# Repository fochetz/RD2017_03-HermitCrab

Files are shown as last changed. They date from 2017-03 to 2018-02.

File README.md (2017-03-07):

# RD2017_03-HermitCrab

N|Solid (https://nodesource.com/products/nsolid)

Hermit Crab is an autonomous Arduino based robot which can interact with people in order to promote a fish restaurant.
Our idea is to build more than one robot with the appearance of hermit crabs that will be able to move, to understand when a person is approaching them and to react hiding under their own shells.
Then they will start slowly to come out from the shell and start to do some movements attracting attention with sound and light.

## Multidisciplinary Course of Robotics and Design - 5th Edition
Professors:
 - Andrea Bonarini, DEIB department, Politecnico di Milano
 - Maximiliano Romero, DPAC department, Università IUAV, Venezia

Tutors: Andrea Brivio, Yael Bendit

## Team
 - Moreno Sardella, master degree student in computer science
 - Luca Fochetta, master degree student in computer science
 - Dimitar Anastasovski, master degree student in computer science
 - Lorenzo Vignati, master degree student in biomedical science
 - Paolo Ritter, master degree student in biomedical science

**... free software, hell yeah!**

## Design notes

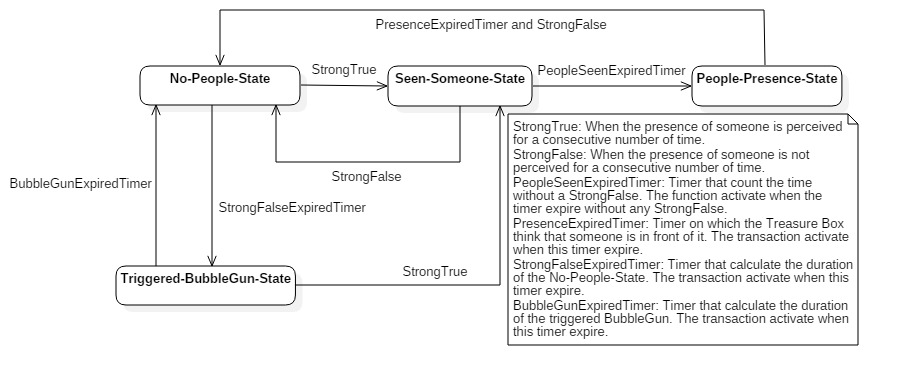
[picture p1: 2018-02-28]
documents/OysterDiagram.jpg

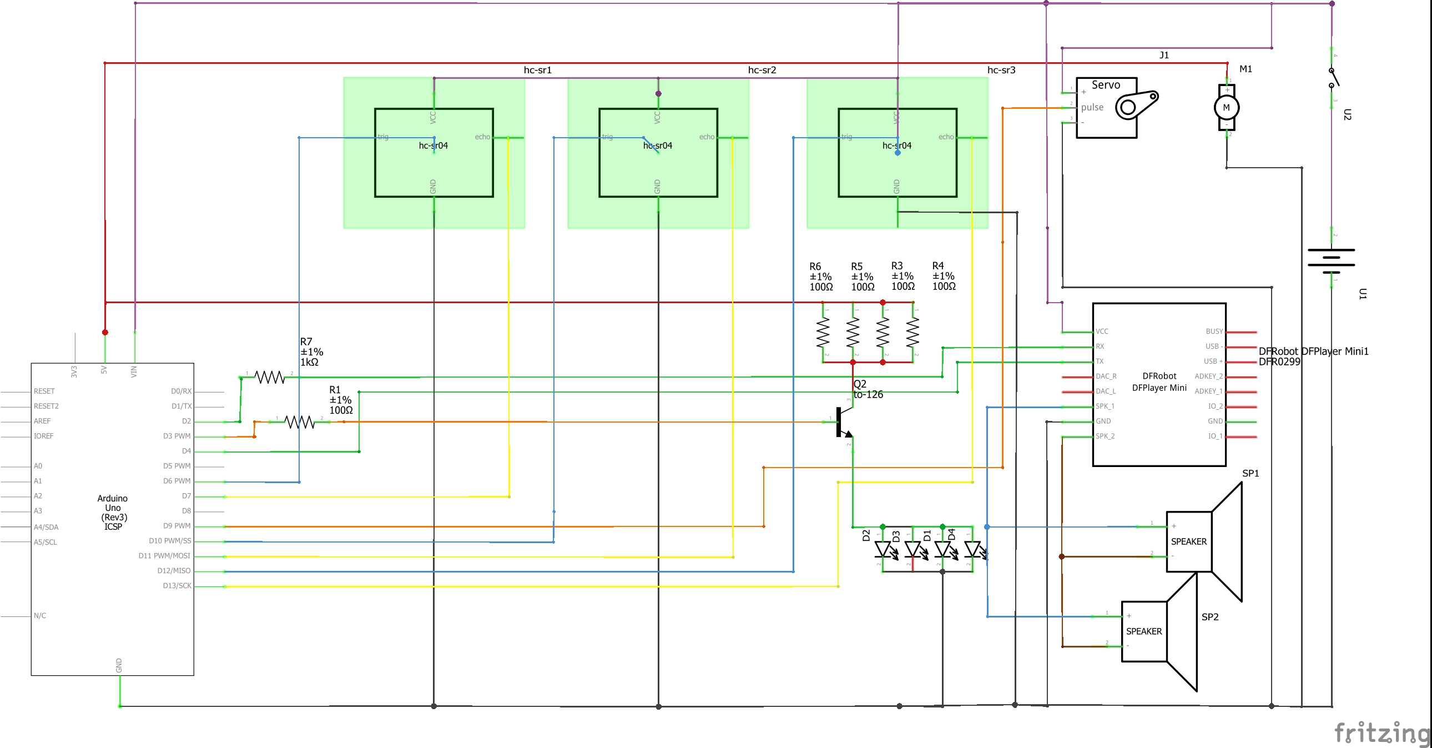
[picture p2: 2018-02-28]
documents/Oyster-schema_schem.jpg

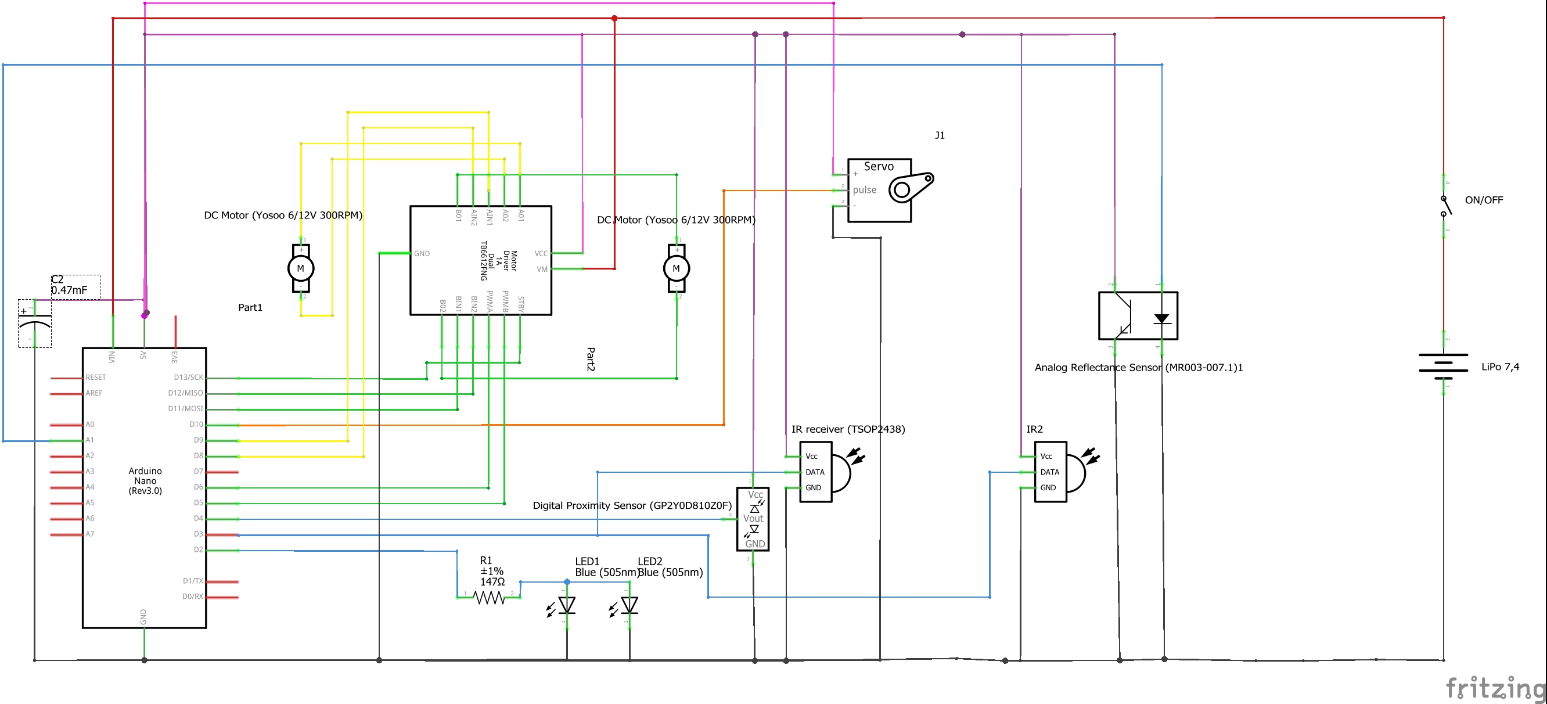
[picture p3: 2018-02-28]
documents/HermitCrab_schem.jpg

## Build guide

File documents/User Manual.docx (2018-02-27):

# User Manual

# Hermit Crab

# Hermit Crub members

# Moreno Sardella, master degree student in computer science and engineering

# Luca Fochetta, master degree student in computer science and engineering

# Lorenzo Vignati, master degree student in biomedical science and engineering

# Paolo Ritter, master degree student in biomedical science and engineering

# Dimitar Anastasovski, master degree student in computer science and engineering

# 1 – General Information

## 1.1 – Overview

Hermit Crab is a product composed of three robots used in a restaurant to attract people. There will be two small Hermit Crabs that will move on a custom menu and a Treasure Box that will be placed close to the menu.

When there is no one in front of the restaurant the Hermit Crabs will run inside the custom menu, meanwhile the Treasure Box will periodically trigger a Bubble Gun.

Instead, when there is someone approaching the restaurant the Treasure Box will perceive them and will do the following operations:

- Communicate with the Hermit Crabs and advise them that someone is approaching.
- Invite the people to go inside the restaurant.

The Hermit Crabs instead will do the following operations when someone is approaching:

- They will become afraid.
- They will run to the border of the menu.
- They will close their eyes and their shells.
- After few seconds they will move on the border of the menu.

## 1.2 – Package’s Component

On this manual will be explained how to properly use yours Hermit Crab. The package is composed of:

- 2 Hermit Crabs
- 2 Shells
- 2 Batteries
- 1 Treasure Box
- 1 Custom Menu
- 1 Battery Charger
- 1 Micro-usb cable
- 1 Power supplier

# 2 – Hermit Crab Installation

## 2.1 – Required Workspace

To properly use the Hermit Crab product, you will need a table that is at least 1x1 m.

## 2.2 – Custom Menu and Hermit Crabs Installation

The custom menu must be on the table unfolded, with the white part on top. The Hermit Crabs must be put on the white part of the menu.

## 2.3 – Treasure Box

The Treasure Box must be put next to the menu (on the left side), with the front side directed to the area where the people will walk. The Box must be closed to a power point to supply it. Then connect the plug.

## 2.4 – Shell Installation

The shell must be put on top of the Hermit Crab “cage” with the bigger part on the front of the hermit (see the image). Then you must delicately push the shell down until it will be fixed with the cage.

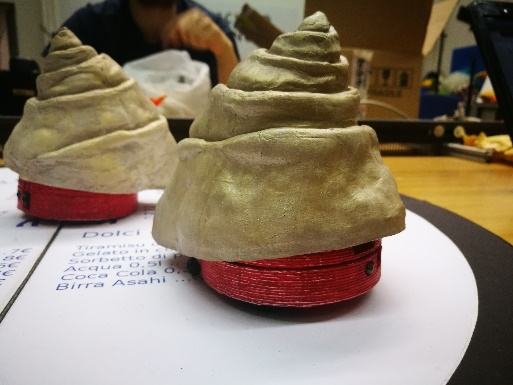
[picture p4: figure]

## 2.5 – Usage

To make the Hermit Crab work, you must turn them on by moving the switch placed on the bottom of them to On. Then you to press the button of the Treasure Box placed on the back of it to On.

## 2.6 – Enjoy

Now you have successfully installed yours Hermit Crab Product. Well Done!

# 3 – Components Replacement

## 3.1 – Battery Removal / Replacement

To replace the battery of a Hermit Crab you have to possess a battery LP-E8(7.4 V).

To Replace/charge the battery, you must follow these steps:

1. Gently remove the shell from the Hermit Crab.
2. Open up the cage.
3. Remove the wood connector from the battery.
4. Remove the battery and charge it or replace the old battery with the new one.
5. Reconnect the wood connector being very careful to the polarity.
6. Move the hermit crab arm in position (Figure 3.1.1) and move down the cage.
7. Gently put the shell on the cage (FOLLOW 2.4 – Shell Installation).

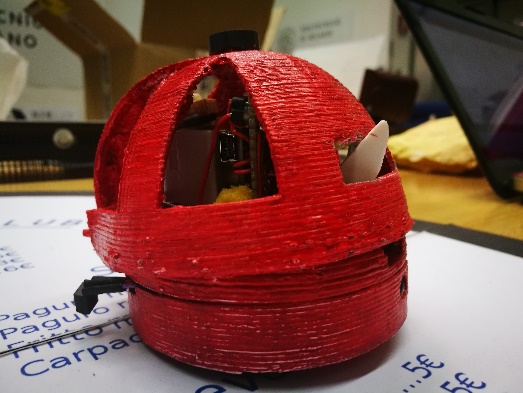
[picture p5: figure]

Figure 3.1.1

## 3.2 – Soap Replacement

To replace the soap on the Treasure Box you have to follow these steps:

1. Lift up the coin’s holder(SEE FIGURE 3.2.1).
2. Slip off the white wire (SEE FIGURE 3.2.2).
3. Pull up the Bubble Gun and slip it off from the trigger (SEE FIGURE 3.2.3).
4. Screw off the tank from the Bubble Gun, fullfill it and screw it on.
5. Put the Trigger in the correct position (SEE FIGURE 3.2.4) and put the Bubble Gun on its housing.
6. Slip on the white wire putting it on the small hole on the trigger (SEE FIGURE 3.2.5).
7. Pulll down the coin’s holder.

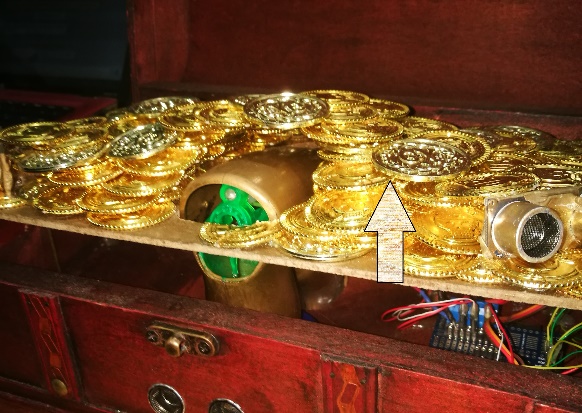
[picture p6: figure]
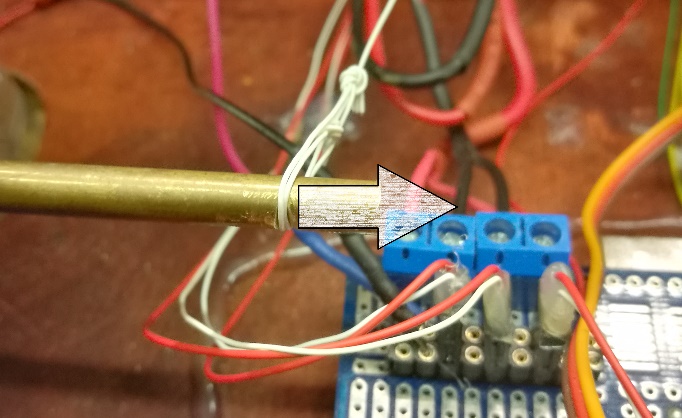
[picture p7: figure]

Figure 3.2.1. Figure 3.2.2.

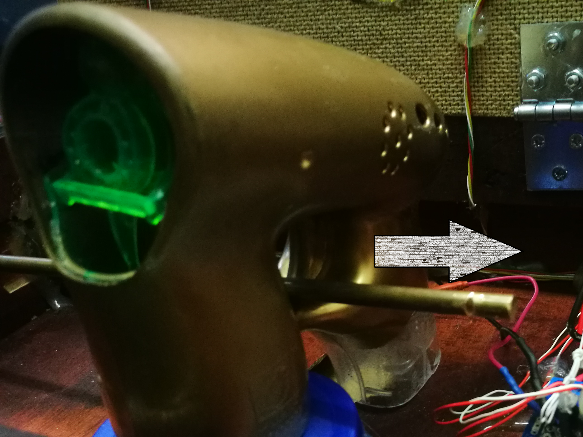
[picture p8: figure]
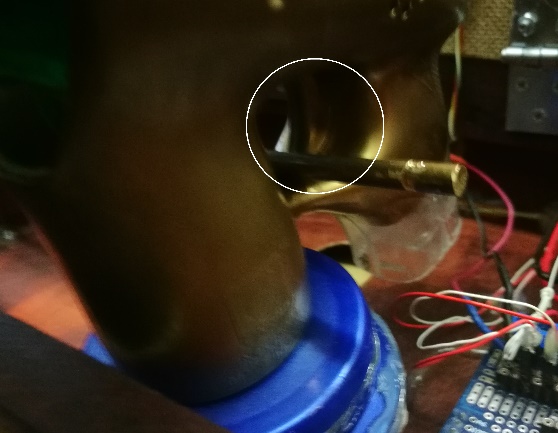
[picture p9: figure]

Figure 3.2.3. Figure 3.2.4.

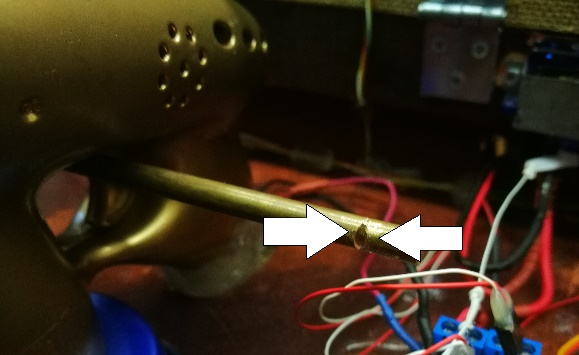
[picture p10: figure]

Figure 3.2.5.

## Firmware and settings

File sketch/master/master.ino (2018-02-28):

#include <SoftwareSerial.h>
#include <DFPlayer_Mini_Mp3.h>
#include <IRremote.h>
#include <NewPing.h>
#include <Servo.h>

//PIN SONAR 1
#define TRIGGER_PIN1 6
#define ECHO_PIN1 7
//PIN SONAR 2
#define TRIGGER_PIN2 10
#define ECHO_PIN2 11
//PIN SONAR 3
#define TRIGGER_PIN3 12
#define ECHO_PIN3 13
//THRESHOLD(IN cm) TO DEFINE IF A PERSON IS CLOSE TO THE OYSTER
#define PRESENCE_THRESHOLD 100
//MAX DISTANCE IN cm TO PING
#define MAX_DISTANCE 100

/*-----------------------------------------
 * SERVO
 ------------------------------------------*/

//PIN BUBBLE GUN SERVO
#define BUBBLEGUN_SERVO_PIN 9

//TIME BETWEEN THE COMMAND OF A MOVEMENT TO A SERVO AND ITS DETACH
#define DETACH_TIME 300
//HOW MUCH TIME THE BUBBLE GUN WILL BE TRIGGERED
#define TRIG_TIME 1000
//TRIG / UNTRIG POSITION OF THE BUBBLE GUN'S SERVO
#define UN_TRIG_POSITION 140
#define TRIG_POSITION 75
/*---------------------------------------
 * END SERVO
 ----------------------------------------*/
//PIN DFPLAYER
#define RX_PIN 4
#define TX_PIN 2

//DEFINE THE DIMENSION OF THE TABLE FOR THE SONAR READING OPERATION
#define NUMBEROFMISSREAD 3

//POSSIBLE STATE OF THE HISTORY PRESENCE TABLE
#define STRONGFALSE 0
#define AMBIGUOUS 1
#define STRONGTRUE 2
//TIME THAT MUST PASS BETWEEN AN UNTRIG OF THE BUBBLE GUN AND THE FOLLOWING TRIG WITHOUT ANY STRONGTRUE IN MEANTIME
#define STRONGFALSE_TIME 5000
//TIME THAT HAVE TO PASS AFTER A STRONGTRUE WITHOUT ANY STRONGFALSE IN ORDER TO SAY THAT SOMEONE IS IN FRONT OF THE OYSTER
#define PEOPLE_SEEN_TIME 250

/*
 * IR COMMUNICATION
 */
//TIME THAT DEFINE FOR HOW MUCH TIME I WILL SEND A PEOPLE PACKET WITHOUT MODIFYING THE STATE
#define UNCHECKED_SENDING_PEOPLE_TIME 5000
//TIME THAT DEFINE FOR HOW MUCH I WILL SEND THE NO PEOPLE PACKET
#define SENDING_NO_PEOPLE_TIME 250

#define PEOPLE_PACKET 0xE0E0906F
#define NO_PEOPLE_PACKET 0xE0E0906A
//DIMENSION IN BIT OF THE PACKET SENT
#define PACKET_DIMENSION 32
#define DELAY_BETWEEN_IR_SENDING 30


#define MIN_VOLUME 15
#define MAX_VOLUME 30
#define DEFAULT_SONG 1
#define PEOPLE_INVITATION 2
#define NUMBER_OF_TRACK_INVITATION 4

int i = 0;
//SONAR READ VALUE
unsigned int cm_sonar1, cm_sonar2, cm_sonar3;
/*-------------------------------------------------------------------------
   TIMER
  -------------------------------------------------------------------------*/
unsigned long people_seen_timer, sending_people_timer, sending_no_people_timer, sonar_waiting_timer = 0;
unsigned long ir_timer = 0, strongfalse_timer = 0, bubble_gun_timer = 0, detach_bubble_gun_timer = 0;

/*-----------------------------------------------------------------------------
   FLAG RELATED TO TIMER
  -----------------------------------------------------------------------------*/
bool timer_flag = false, send_people_flag = false, send_no_people_flag = false;
bool strongfalse_flag = false, bubble_gun_trig = false;
bool detach_bubble_gun_flag = false;

//TABLE HISTORY OF PEOPLE PRESENCE
bool people_presence_history [NUMBEROFMISSREAD] = {false, false};

//Used to store the actual state of presence table : STRONGTRUE, STRONGFALSE, AMBIGUOUS (WHEN A READ SEE PRESENCE AND THE FOLLOWING/PREVIOUS DOES NOT)
int presence_table_state = 0;
enum state_type {
  BUBBLE_GUN_TRIGGERED_STATE,
  NO_PEOPLE_STATE,
  PEOPLE_SEEN_STATE,
  PEOPLE_PRESENCE_STATE
};

//ACTUAL STATE VARIABLE
state_type actual_state = NO_PEOPLE_STATE;

//first trigger pin, second echo pin
NewPing sonar1(TRIGGER_PIN1, ECHO_PIN1, MAX_DISTANCE);
NewPing sonar2(TRIGGER_PIN2, ECHO_PIN2, MAX_DISTANCE);
NewPing sonar3(TRIGGER_PIN3, ECHO_PIN3, MAX_DISTANCE);

//----------RX arduino ---> TX dfPlayer
SoftwareSerial mySerial(RX_PIN, TX_PIN); // RX, TX
byte dfplayer_volume = 30;

//sender object, pin 3

IRsend ir_sender;


//Servo variable:
Servo trigger_bubble_gun;


void setup() {
  //mp3 serial
  dfplayer_volume = 30;
  mySerial.begin (9600);
  mp3_set_serial (mySerial);
  Serial.begin(115200);
  //mp3 set volume
  mp3_set_volume (dfplayer_volume);
  mp3_play (DEFAULT_SONG);
  un_trig_bubble_gun();

  //for test:
  //actual_state = PEOPLE_PRESENCE_STATE;
  //people_presence_history[NUMBEROFMISSREAD-1] = true;
}


void loop() {
  sonars_perceiving();
  update_people_presence_history();
  Serial.println (cm_sonar1);
  Serial.println (cm_sonar2);
  Serial.println (cm_sonar3);
  presence_table_state = check_presence_table();
  switch (presence_table_state)
  {
    case STRONGTRUE : Serial.println("STRONGTRUE"); break;
    case STRONGFALSE : Serial.println("STRONGFALSE"); break;
    case AMBIGUOUS : Serial.println("AMBIGUOUS"); break;
  }

  switch (actual_state)
  {
    case NO_PEOPLE_STATE:
      Serial.println("NO_PEOPLE_STATE");
      no_people_state_action();
      break;
    case BUBBLE_GUN_TRIGGERED_STATE:      
      Serial.println("BUBBLE_GUN_TRIGGERED_STATE");
      bubble_gun_triggered_action();
      break;
    case PEOPLE_SEEN_STATE:      
      Serial.println("PEOPLE_SEEN_STATE");
      people_seen_action();
      break;
    case PEOPLE_PRESENCE_STATE:
      Serial.println("PEOPLE_PRESENCE_STATE");
      people_presence_action();
      break;
    default:
      break;

  }
  if (send_no_people_flag == true)
  {
    // send no people packet
    send_no_people_packet();
    
    if ( expired_timer(sending_no_people_timer , SENDING_NO_PEOPLE_TIME))
    {
      Serial.println("Stop no people packet");
      send_no_people_flag = false;
    }
  }
  
  if (detach_bubble_gun_flag)
  {
    if (expired_timer(detach_bubble_gun_timer , DETACH_TIME))
    {
      trigger_bubble_gun.detach();
      detach_bubble_gun_flag=false;
    }
  }
}
/*-------------------------------------------------
   NO PEOPLE STATE ACTION
  --------------------------------------------------*/

void no_people_state_action()
{
  switch (presence_table_state)
  {
    case AMBIGUOUS:
    case STRONGFALSE:
      if (strongfalse_flag == false && presence_table_state == STRONGFALSE)
      {
        strongfalse_flag = true;
        strongfalse_timer = millis();
      }
      else if ( strongfalse_flag == true && expired_timer(strongfalse_timer, STRONGFALSE_TIME))
      {
        strongfalse_flag = false;
        trig_bubble_gun();
        actual_state = BUBBLE_GUN_TRIGGERED_STATE;
        bubble_gun_timer = millis();
      }
      break;
    case STRONGTRUE:
      if (strongfalse_flag == true) strongfalse_flag = false;
        people_seen_timer = millis();
        actual_state = PEOPLE_SEEN_STATE;
      break;
    default:
      break;
  }
}
/*-----------------------------------------
 * BUBBLE GUN TRIGGERED ACTION 
 ------------------------------------------*/
 
void bubble_gun_triggered_action()
{
  switch(presence_table_state)
  {
    case AMBIGUOUS:
    case STRONGFALSE:
      if(expired_timer(bubble_gun_timer, TRIG_TIME))
      {
        Serial.println("DISABLE BUBBLEGUN");
        un_trig_bubble_gun();
        actual_state = NO_PEOPLE_STATE;
      }
      break;
     case STRONGTRUE:
      un_trig_bubble_gun();
      actual_state = PEOPLE_SEEN_STATE;
      break;
  }
}
/*-------------------------------------------------------
 * PEOPLE SEEN ACTION
 --------------------------------------------------------*/
byte played_track = PEOPLE_INVITATION;
void people_seen_action()
{
  switch (presence_table_state)
  {
    case STRONGFALSE:
      actual_state = NO_PEOPLE_STATE;
      break;
    case AMBIGUOUS:
    case STRONGTRUE:
      if (expired_timer(people_seen_timer, PEOPLE_SEEN_TIME))
      {
        send_no_people_flag = false;
        if(played_track >= (PEOPLE_INVITATION + NUMBER_OF_TRACK_INVITATION))
          played_track = PEOPLE_INVITATION;
        mp3_play (played_track);
        mp3_single_loop (true);
        played_track++;
        Serial.println("Playing " + played_track);
        actual_state = PEOPLE_PRESENCE_STATE;        
        sending_people_timer = millis();
      }
      break;
    default:
      break;


  }
}
/*-------------------------------------------------
 * PEOPLE PRESENCE ACTION
 --------------------------------------------------*/
void people_presence_action()
{
  if (expired_timer(sending_people_timer,UNCHECKED_SENDING_PEOPLE_TIME))
  {
    switch(presence_table_state)
    {
        case STRONGTRUE:
          sending_people_timer = millis();
          break;
        case AMBIGUOUS:
          send_people_packet();
          break;
        case STRONGFALSE:
          send_no_people_flag = true;
          sending_no_people_timer = millis();
          mp3_play (DEFAULT_SONG);
          mp3_single_loop (true);
          actual_state = NO_PEOPLE_STATE;
          break;
    }
  }
  else
  {
    send_people_packet();
  }
}
// GIVEN A TIMER AND AN INTERVAL, RETURN IF THE TIME IS PASSED(TRUE) OR NOT(FALSE)

bool expired_timer(unsigned long timer, unsigned int interval)
{
  return (millis() - timer > interval);
}

//UPDATE THE PEOPLE PRESENCE HISTORY USING THE NEW VALUE FROM THE SONAR

void update_people_presence_history()
{
  //SHIFTING OPERATION
  for(int i = 1; i < NUMBEROFMISSREAD; i++) people_presence_history[i-1] = people_presence_history[i];
  
  if (presence_perceived(cm_sonar1) || presence_perceived(cm_sonar2) || presence_perceived(cm_sonar3))
  {
    people_presence_history [NUMBEROFMISSREAD - 1] = true;
  }
  else
  {
    people_presence_history[NUMBEROFMISSREAD - 1] = false;
  }
}

/* RETURN A VALUE BASED ON THE VALUES ON THE PEOPLE PRESENCE HISTORY BY FOLLOWING THIS RULES:
  ALL TRUE     ------> STRONGTRUE
  ALL FALSE    ------> STRONGFALSE
  MIXED CASE   ------> AMBIGUOUS
*/
int check_presence_table()
{ 
  bool first_table_value = people_presence_history[0];
  for(int i = 1; i <NUMBEROFMISSREAD; i++)
  {
    if (people_presence_history[i] != first_table_value) return AMBIGUOUS;
  }
  if(first_table_value) return STRONGTRUE;
  else return STRONGFALSE;
}

//ACTIVATE THE BUBBLE GUN BY MOVING THE SERVO TO A CERTAIN POSITION

void trig_bubble_gun()
{
  trigger_bubble_gun.attach(BUBBLEGUN_SERVO_PIN);
  trigger_bubble_gun.write(TRIG_POSITION);
  //detach_bubble_gun_flag = true;
  //detach_bubble_gun_timer = millis();
}

//DEACTIVATE THE BUBBLE GUN BY MOVING THE SERVO TO A CERTAIN POSITION

void un_trig_bubble_gun()
{
  trigger_bubble_gun.attach(BUBBLEGUN_SERVO_PIN);
  trigger_bubble_gun.write(UN_TRIG_POSITION);
  detach_bubble_gun_flag = true;
  detach_bubble_gun_timer = millis();
}

//PERCEIVE DISTANCE FROM THE SONAR

void sonars_perceiving()
{
  cm_sonar1 = sonar1.ping_cm();
  cm_sonar2 = sonar2.ping_cm();
  cm_sonar3 = sonar3.ping_cm();  
}


bool presence_perceived( unsigned int distance)
{
  if (distance > 0 && distance < PRESENCE_THRESHOLD) return true;
  else return false;

}

// SEND THE PACKET TO THE HERMIT TELLING THAT THE PERSON/PEOPLE IN FRONT OF THE OYSTER WENT AWAY

void send_no_people_packet()
{
  
  if (expired_timer(ir_timer,DELAY_BETWEEN_IR_SENDING))
  {
    Serial.println("No People Packet");
    ir_sender.sendSony(NO_PEOPLE_PACKET, PACKET_DIMENSION);
    ir_timer = millis();
  }
}

//SEND THE PACKET TO THE HERMIT TELLING THAT THERE IS SOMEONE IN FRONT OF THE OYSTER

void send_people_packet()
{
  if (expired_timer(ir_timer,DELAY_BETWEEN_IR_SENDING))
  {
    Serial.println("People Packet");
    ir_sender.sendSony(PEOPLE_PACKET, PACKET_DIMENSION);
    ir_timer = millis();
  }
}

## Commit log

2017-03-29 Master documents (#7)
    * First ideas and group roles have been defined
    * List of materials has been added
    [materials.ods]
2017-05-17 Prototype4 slave sketch (#17)
    * Hermit electronic scheme has been added
    * final 3rd prototype slave sketch
    * first draft of 4th prototype slave sketch
    * Fritzing schema has been removed from the PR
2017-05-17 Prototype4 slave sketch (#18)
    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
2017-05-17 Documents have been removed (#19)
    [materials.ods]
2017-05-17 Prototype4 (#20)
    * Documents have been removed
    * Line following changed to the internal side
2018-02-20 Updated Document
    [Oyster-schema.fzz]
2018-02-23 Updated Report and Oyster Schema
    Made some integration to the report describing some step and modified
    the Oyster Schema power supplier.
    [Oyster-schema.fzz]
2018-02-27 Updated Sketch (Sonar issue)
    [master.ino]
2018-02-27 Updated User Manual and Reduced timer on the Master Sketch
2018-02-28 Final Master Sketch
    [Oyster-schema.fzz]
2018-02-28 Added Capacitor on HermitCrab Schema
    [HermitCrab.fzz]
